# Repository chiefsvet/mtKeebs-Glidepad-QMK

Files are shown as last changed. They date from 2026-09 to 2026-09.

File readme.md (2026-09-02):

## mtKeebs Glidepad

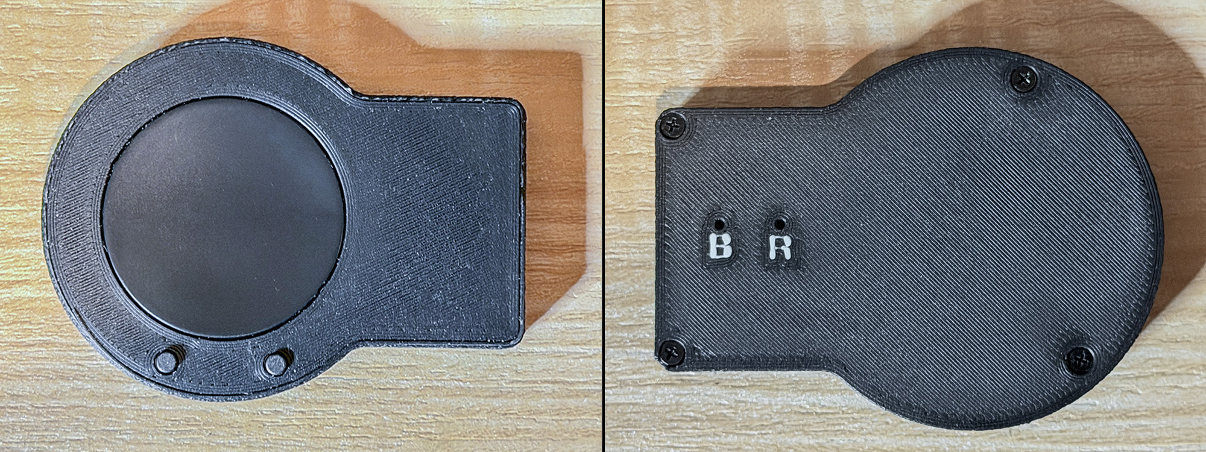
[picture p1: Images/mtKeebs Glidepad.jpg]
Image the top and bottom sides of the Glidepad


The mtKeebs Glidepad is my version of the ScottoCirque trackpad. Check out Joe Scotto's [YouTube video](https://www.youtube.com/watch?v=AhoCn2nf1GU) and his [website](https://scottokeebs.com/blogs/macropads/scottocirque) for more information. He calls himself "the handwiring guy" because the majority of his builds are hand-wired, although he's been doing some PCB builds, too. If you're new to electronics and custom mechanical keyboards like me, check out his YT channel. I learned 99% of what I know from his channel.

The ScottoCirque uses a 40 mm trackpad with a flat overlay, but I wanted to use a curved overlay. The 40 mm size was on backorder everywhere I've looked, so I purchased the 35 mm version. I originally put the trackpad into a custom hand-wired mechanical keyboard that I was already in the process of designing/building that was using CircuitPython at the time his video came out, but I had a lot of issues with implementation of the trackpad driver. I was able to get the cursor to move fairly accurately, but tap to click was incredibly unreliable (registering only 1 in 10 taps) and I couldn’t get scrolling to work. I also tried using ZMK firmware for the trackpad, but was having a lot of issues with tracking directionality and again I couldn’t get scrolling to work. I will eventually go back and try ZMK again since I really prefer to have a wireless option for connecting keyboards to my computer.

After these two failures, I decided to start from scratch based off Joe Scotto’s version using a wired build and QMK. Like he states in his video about his version, the design here is just for testing purposes. It will eventually be built into a custom keyboard with better buttons for left and right click. 

**Some changes in my build compared to the ScottoCirque:**
1. 35 mm trackpad with a curved overlay
2. I had a Waveshare RP2040 on hand so I used that board instead
3. I didn’t want screws visible form the top so I designed my own case with screws inserting from the bottom
4. There are two small holes over the boot and reset buttons for access while the case is closed. The RP2040 is mounted upside down so the buttons face the bottom of the case.
4. Since I was having trouble with tap to click previously, I added two momentary push buttons to use as backup for left and right click. Turns out that was a wise choice because I still struggle with tap to click. I’ll redesign them when this goes into a keyboard. 
5. I still can’t get scrolling to work just using my finger on the trackpad, so I had Claude.ai create custom code for the scrolling behavior and made the right click button have a press and hold feature to get the scroll feature to work. If I still can't scrolling to work without it, I'll probably add a third (center) button that I can press with my thumb and use my index finger to scroll on the trackpad.

---

### Bill of Materials

| Part | Qty | Notes |
| --- | --- | --- |
| [Waveshare RP2040-Zero](https://www.waveshare.com/rp2040-zero.htm?srsltid=AfmBOorBt2v1roA5Ej6xlDoV228nK-XgI2wQrG1-7OLUrxRTVEoYe3wA) or similar third-party board | 1 | RP2040, wired only, physical boot loader & reset buttons on board |
| [Cirque Glidepoint Trackpad](https://www.mouser.com/en/ProductDetail/Cirque/TM035035-2024-003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), 35mm circular, curved overlay, SPI | 1 | Be sure to get the version with the curved overlay and that there's a resistor at R1 for **SPI** not I2C (required by this build). The case is designed for the version with the curved overlay and not the flat overlay. |
| [Tactile Push Button Micro Momentary Switches](https://www.amazon.com/dp/B09R3ZPWJ7?ref=ppx_yo2ov_dt_b_fed_asin_title&th=1), 6x6x6 mm, 2-pin | 4 | For left & right click buttons, soft\\\_off power, and reset |
| [M2 Heat Set Threaded Insert](https://www.amazon.com/dp/B0CS6XJSSL?ref_=ppx_hzsearch_conn_dt_b_fed_asin_title_2&th=1) | 4 | - |
| [M2 Phillips Flathead Screws](https://www.amazon.com/dp/B082XXW76M?ref_=ppx_hzsearch_conn_dt_b_fed_asin_title_7&th=1), 6mm | 4 | - |
| [3M Double-Sided Tape](https://www.amazon.com/dp/B0DJNVVPY1?ref_=ppx_hzsearch_conn_dt_b_fed_asin_title_1&th=1), 1/2-inch  | 1 | Be sure yours is compatible with electronics. Only a small piece is needed to secure RP2040 to the case.  |
| [28 AWG Stranded Hook Up Wire](https://www.amazon.com/dp/B073RDKRBX?ref_=ppx_hzsearch_conn_dt_b_fed_asin_title_8&th=1) | * | Various colors & lengths |
| Soldering iron & solder | 1 | - |

---

### Wiring Guide

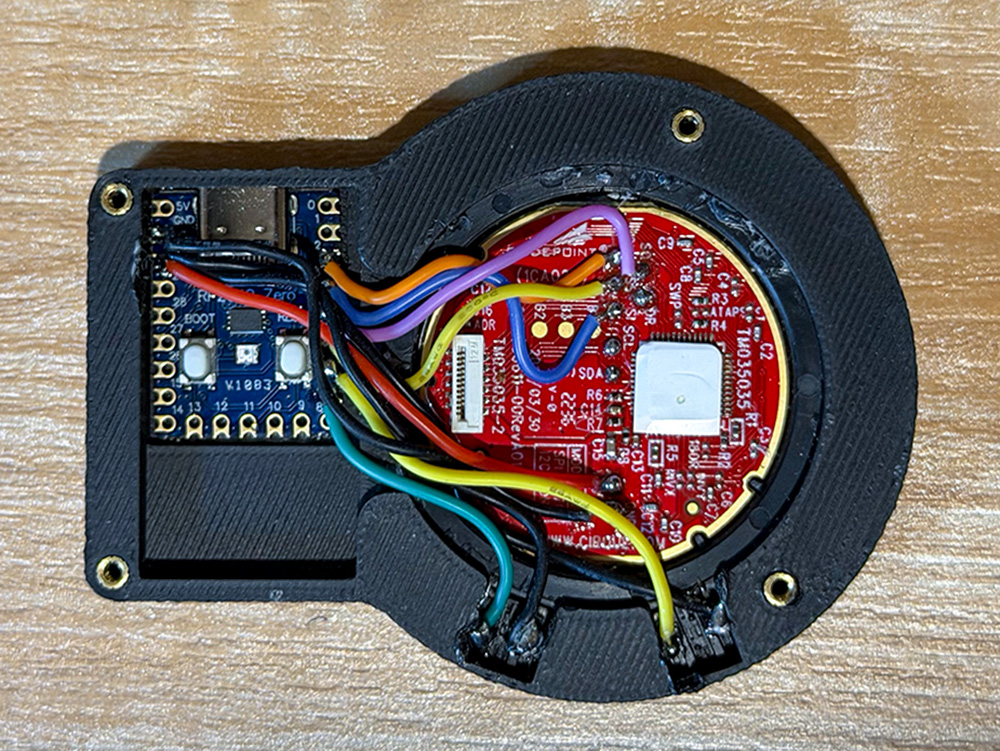
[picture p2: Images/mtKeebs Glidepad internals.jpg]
Image the top and bottom sides of the Glidepad


| Signal | RP2040 | Connects to...
| --- | --- | --- |
| SPI SCK | GP2 | SCK on trackpad |
| SPI MOSI | GP3 | SI on trackpad |
| SPI MISO | GP4 | SO on trackpad |
| Chip Select | GP5 | SS (same as CS for other manufacturers) |
| 3.3V | 3v3 | VDD |
| GND | GND | GND |
| DR (Data Ready) | *not connected* | Not needed in this build |
| Left button click | GP6 | One pin of left momentary button |
| Left button ground | GND | Other pin of left momentary button |
| Right button click | GP7 | One pin of right momentary button |
| Right button ground  | GND | Other pin of right momentary button |

**NOTES**
- The RP2040-Zero only has one ground pin so the ground wire from the trackpad and the ground wires from the two momentary buttons need to be tied together and soldered to the ground pin on the RP20240.
- "CS" and "SS" are the same signal — different vendors label it differently.
- The trackpad's bus-mode jumper (R1, 470kΩ) must be populated for SPI. No resistor there means the board is in I2C mode and the firmware in this repo won’t work. Trackpad comes pre-populated with the resistor so it’s in SPI mode. If you need to use I2C for your build, you’ll need to remove the resistor and rewrite the code.

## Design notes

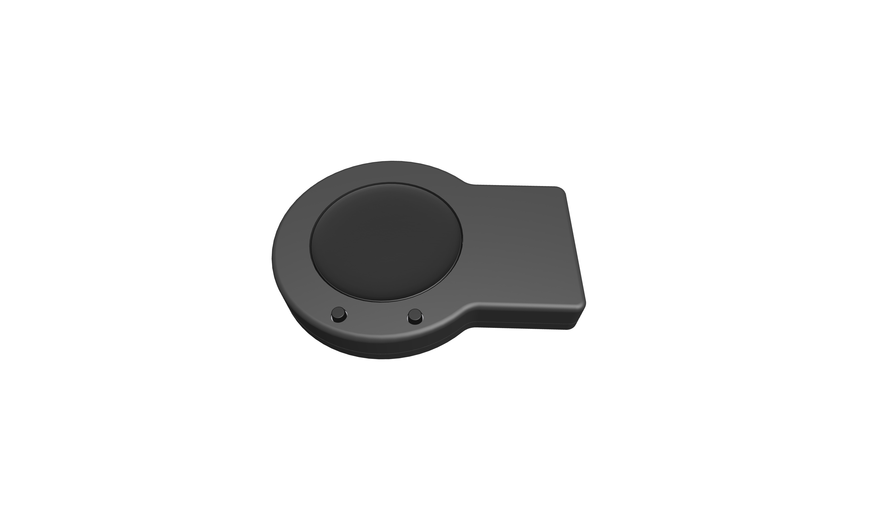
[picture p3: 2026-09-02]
Images/mtKeebs Glidepad 3D render top front.jpeg

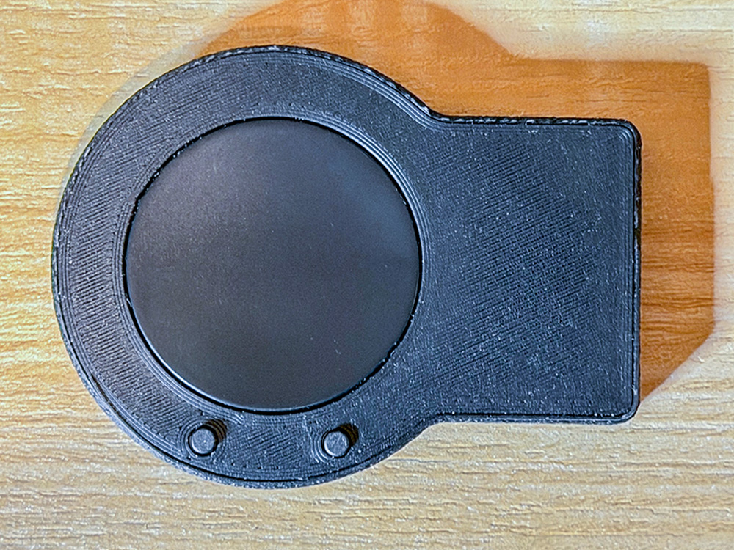
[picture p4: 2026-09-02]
Images/mtKeebs Glidepad top.jpg

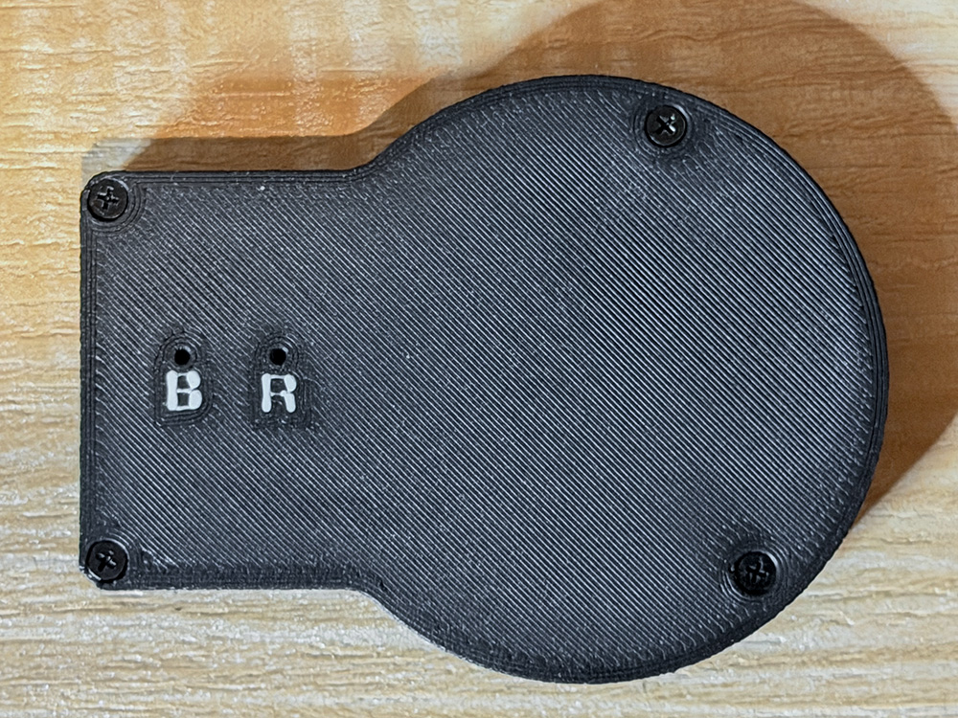
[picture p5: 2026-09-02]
Images/mtKeebs Glidepad bottom.jpg

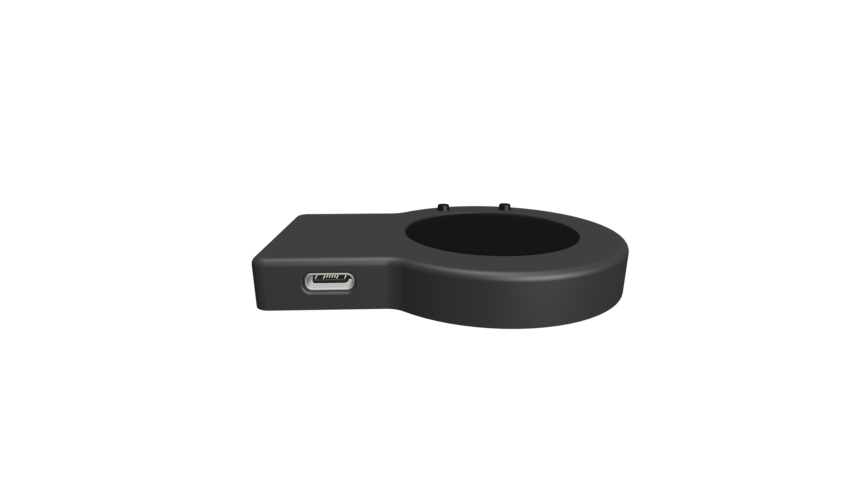
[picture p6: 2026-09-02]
Images/mtKeebs Glidepad 3D render top back.png

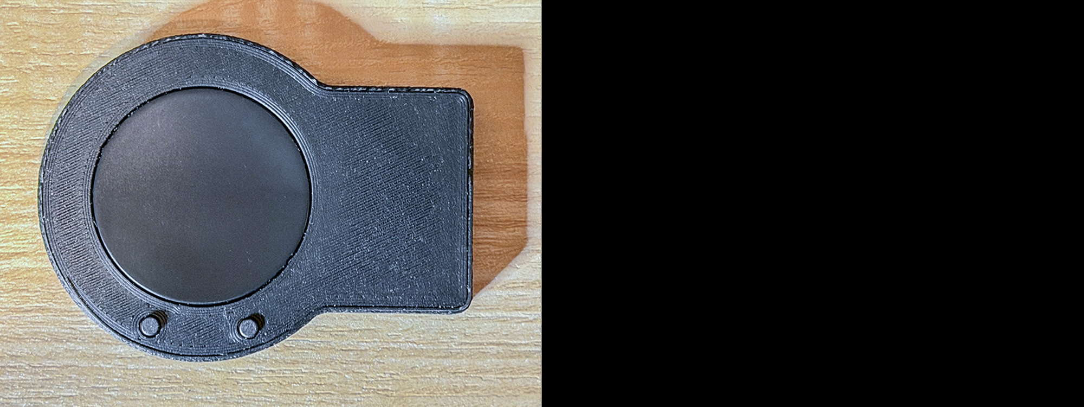
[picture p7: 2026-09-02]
QMK Code Files/image.png

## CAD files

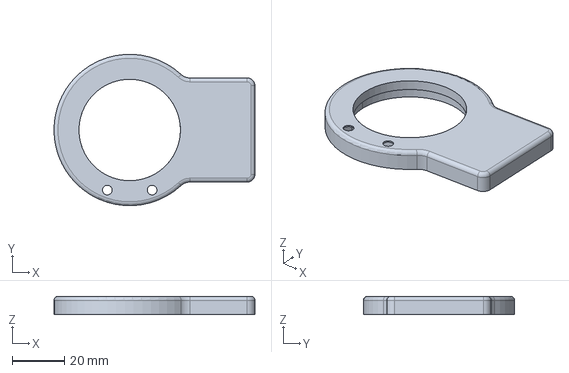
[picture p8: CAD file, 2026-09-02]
Case/mtKeebs Glidepad Case Top.step
77.0 x 57.9 x 7.00 mm

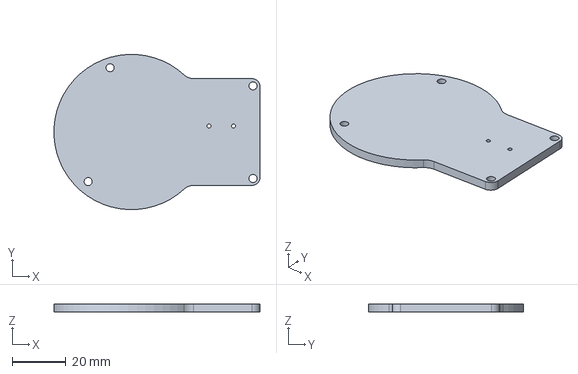
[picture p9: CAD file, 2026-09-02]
Case/mtKeebs Glidepad Case Bottom.step
77.0 x 57.9 x 3.00 mm

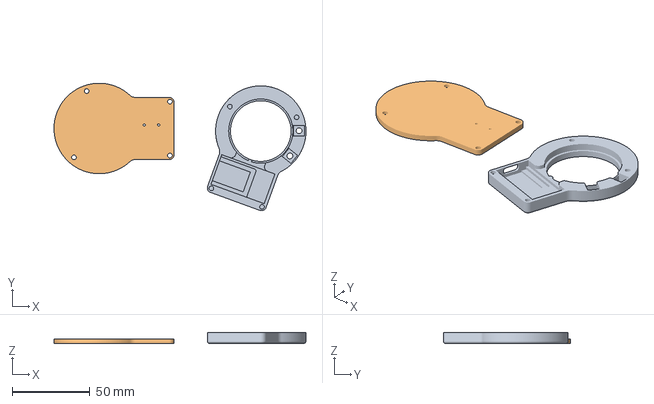
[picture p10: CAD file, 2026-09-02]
Case/mtKeebs Glidepad Case Top & Bottom.3mf
161.7 x 81.8 x 7.00 mm
Top
Bottom

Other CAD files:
Case/mtKeebs Glidepad Case Bottom.3mf
Case/mtKeebs Glidepad Case Bottom.stl
Case/mtKeebs Glidepad Case Top.3mf
Case/mtKeebs Glidepad Case Top.stl

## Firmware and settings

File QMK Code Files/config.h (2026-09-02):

#pragma once

// =====================================================================
// SPI bus wiring for the Cirque Pinnacle (GlidePoint) trackpad module.
// No SPI_DRIVER override needed here -- with no BOARD set in rules.mk,
// QMK's default RP2040 profile already assigns SPI_DRIVER = SPID0 and
// enables that peripheral. We only need to override the actual pins to
// match how the board is physically wired.
// =====================================================================
#define SPI_SCK_PIN GP2
#define SPI_MOSI_PIN GP3
#define SPI_MISO_PIN GP4
#define POINTING_DEVICE_CS_PIN GP5

// =====================================================================
// Cirque Pinnacle / GlidePoint 40mm circle trackpad settings
// (updated from 35mm -- see calibration note below)
// =====================================================================
#define CIRQUE_PINNACLE_DIAMETER_MM 40

// The X/Y bounds below were calibrated for the ORIGINAL 35mm module and
// this specific case fit -- they do NOT necessarily carry over to a new
// 40mm module, even though it's electrically the same sensor family.
// Manufacturing tolerance between individual units, plus how the new
// module physically sits in the case, can shift the practical reachable
// range. Re-run the calibration sweep with the 40mm module wired up:
//   1. Uncomment CIRQUE_PINNACLE_REACHABLE_CALIBRATION below, reflash
//   2. `qmk console`, then firmly sweep to each edge (left/right/top/
//      bottom/diagonals) a few times
//   3. Watch xLo/xHi/yLo/yHi until they stop climbing
//   4. Update the 4 defines below with the new numbers, then comment
//      CIRQUE_PINNACLE_REACHABLE_CALIBRATION back out
// Leaving the old 35mm numbers in for now as a rough starting point --
// tap-to-click and cursor movement will still work with these, just
// not as precisely tuned to the new pad's real edges until recalibrated.
#define CIRQUE_PINNACLE_X_LOWER 300
#define CIRQUE_PINNACLE_X_UPPER 1750
#define CIRQUE_PINNACLE_Y_LOWER 140
#define CIRQUE_PINNACLE_Y_UPPER 1365
// #define CIRQUE_PINNACLE_REACHABLE_CALIBRATION

// Left undefined -> defaults to CIRQUE_PINNACLE_ABSOLUTE_MODE, which is
// what the known-working firmware this is based on uses. Cursor movement
// works normally in this mode either way.
// #define CIRQUE_PINNACLE_POSITION_MODE

#define CIRQUE_PINNACLE_TAP_ENABLE

// Circular/perimeter scroll (POINTING_DEVICE_GESTURES_SCROLL_ENABLE) is
// intentionally NOT defined here. That gesture only checks touch
// position at the exact moment of first contact, which doesn't fit a
// pad where your finger always enters from roughly the same spot --
// no threshold tuning can fix that mismatch. Scroll is instead handled
// in keymap.c via a hold-to-scroll button modifier (see
// pointing_device_task_user), which works regardless of where on the
// pad you touch down.

// Optional: tap the upper-right corner (partially off the sensor) to
// right-click via gesture, on top of tap-to-click above. Uncomment if
// you want tap-based right click in addition to the GP7 hardware button.
// #define CIRQUE_PINNACLE_SECONDARY_TAP_ENABLE

// Orientation adjustments -- tune these to match how you physically
// mounted the pad. ROTATION_180 was confirmed correct for this build
// (moving finger right/up correctly moves the cursor right/up).
#define POINTING_DEVICE_ROTATION_180
// #define POINTING_DEVICE_INVERT_X
// #define POINTING_DEVICE_INVERT_Y

// --- TEMPORARY: verbose driver debug output, remove once scroll works ---
#define POINTING_DEVICE_DEBUG
